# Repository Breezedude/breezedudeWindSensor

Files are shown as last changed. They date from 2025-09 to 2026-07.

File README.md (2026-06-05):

# BreezeDude Wind Sensor
### An open source low power FANET wind data transmitter.

Map of almost all wind stations: [breezedude.de](https://breezedude.de/)

### [Setup Guide & Tools](https://install.breezedude.de/)

For more info and documentation see the [Wiki](https://github.com/Breezedude/breezedudeWindSensor/wiki) and also [Discussion](https://github.com/Breezedude/breezedudeWindSensor/discussions)

PCB files have been moved to [this repo](https://github.com/Breezedude/breezedudeWindSensor-pcb)

----
<p align="center">
  <
  Breezedude Windstation
  Breezedude Windstation <br>
  <br>
</p>

A low cost FANET wind station using Ecowitt WS80/WS85 ultrasonic or DAVIS 6410 analog sensor.     
USB MSC Settings file and Drag&Drop Firmware upgrade. 

- Wind sensor: Ecowitt WS80/WS85 or analog with reed/potentiometer (e.g. DAVIS 6410)
- Barometric pressure sensor: **HP303B**, BMP280, BMP3xx or SPL06-001
- LoRa module: RFM95W (SX1276), G-NiceRF SX1262, **LLCC68**
- Antenna connector: SMA
- Microcontroller: SAMD21
- Connectivity: USB-C, I2C, 2x UART
- Battery: 1S Li-Ion 16340 750mAh (or 1-3x 18650 external)
- Solar: 5V
- PCB Size: 53x22mm

Currently using a 60x60 5V solar panel.     
Avg. power consumption at 40s send interval @3.7V battery: 0.4mA with analog sensor, 0.80mA with WS85, 1.22mA with WS80
 
Based on SMAD21 using [adafruits samd core](https://github.com/adafruit/ArduinoCore-samd) and itsybitsy M0 variant definitions and [bootloader](https://github.com/adafruit/uf2-samdx1).     

#### Related projects and inspiration:
* https://github.com/gereic/GXAirCom
* https://github.com/jgromes/RadioLib
* https://github.com/3s1d/fanet-stm32

If you like this project



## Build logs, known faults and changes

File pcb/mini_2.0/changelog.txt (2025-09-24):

2025-09-24:
V2.3:
* Added 10k pullup to Ssensor UART RX to aboid wakeup when no sensor is connected/cable failiure
* Replaced CN3063 with TP4057 for better avaliability.
* Moved SWD connector for better acessibility
* RF optimisation

2025-04-17:
V2.2:
* economic version with HP203B barometer and Vollgo CC68 868MHz LoRa radio module

2024-12-18: 
Mini V2.0
* Based on alpha 1.4, remade in KiCAD
* Removed heater support (DCDC)
* Changed to linear PV charger (CN 3063)
* TQPF48 package for SAMD21 (cheaper on JLCPCB, better thermal stress durability)
* TVS diodes for all external wiring
* BMP388 baro option
* Second (red) LED for error display
* Onboard battery holder for 16340 (CR123A size)

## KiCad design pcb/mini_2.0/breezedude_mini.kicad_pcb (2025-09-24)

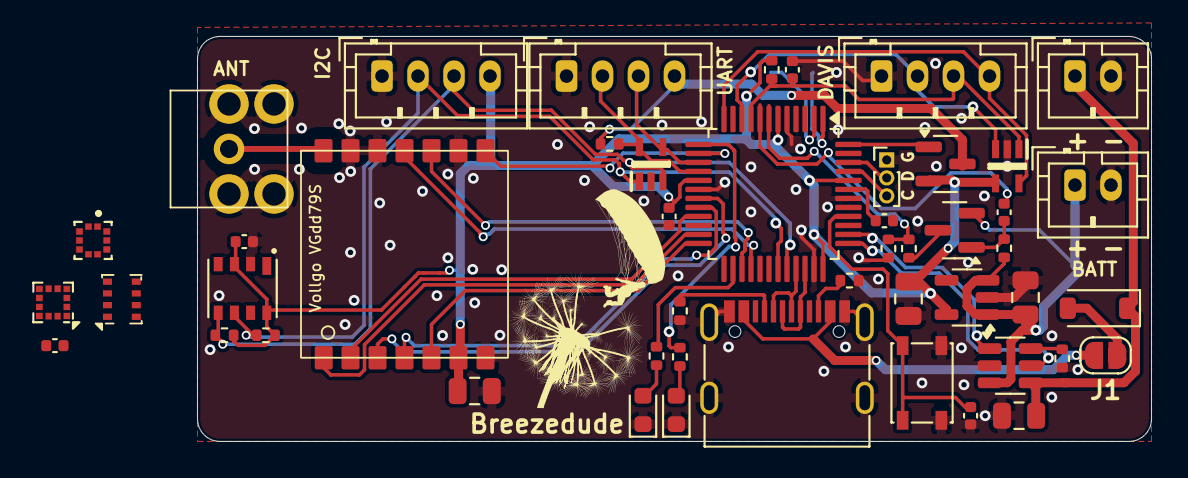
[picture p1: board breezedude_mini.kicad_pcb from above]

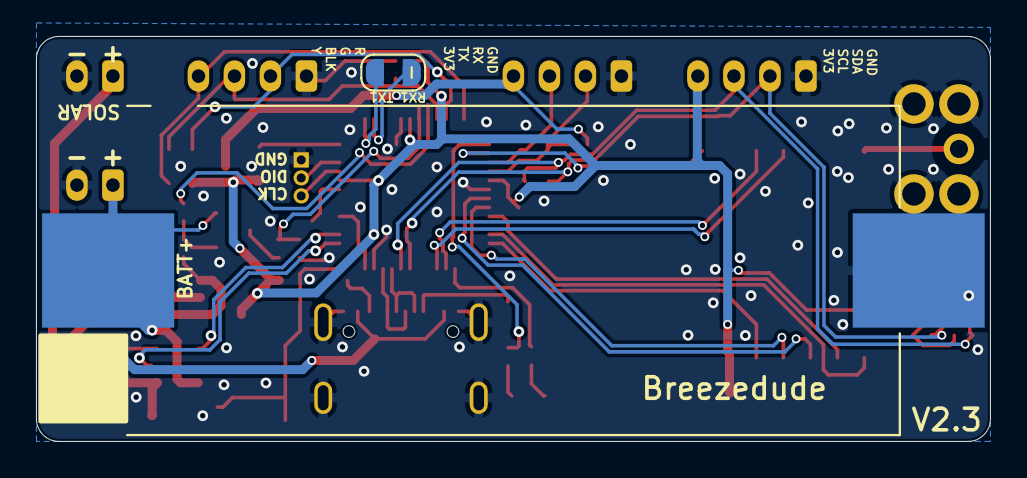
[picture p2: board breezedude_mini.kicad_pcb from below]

Board: 2 copper layers, 53.0 x 22.5 mm, 50 parts (2 on the bottom side), 46 nets.

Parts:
AE1: Antenna_Shield; sma_edge_6.5mm_vert
BT1: 1050; BAT_1050
C1, C3, C4, C12: 47u 6.3V; C_0805_2012Metric
C2, C6, C8: 10u 6.3V; C_0402_1005Metric
C5, C9, C11: 100n 16V; C_0402_1005Metric
C10: 220n 16V; C_0402_1005Metric
D1, D2: SMF3.3.TCT; SOT65P210X110-5N
D3: LED blue; LED_0603_1608Metric
D4: LED red; LED_0603_1608Metric
D5: Diode; D_SOD-123
J1, J6: Conn_01x02_Pin; JST_PH_B2B-PH-K_1x02_P2.00mm_Vertical
J2, J3, J5: Conn_01x04_Pin; JST_PH_B4B-PH-K_1x04_P2.00mm_Vertical
J4: Conn_01x03_Pin; PinHeader_1x03_P1.00mm_Vertical
J7: USB_C_Receptacle_USB2.0_16P; USB_C_Receptacle_G-Switch_GT-USB-7010ASV
J8: Conn_01x02_Pin; SolderJumper-2_Open_Gap1mm
JP1: SolderJumper_2_Open; SolderJumper-2_P1.3mm_Open_RoundedPad1.0x1.5mm
Q1, Q2: P-MOS; SOT-23
R1, R3, R12: 10k; R_0402_1005Metric
R2, R5: 100k; R_0402_1005Metric
R4: 330k; R_0402_1005Metric
R6: 470; R_0402_1005Metric
R7: 200; R_0402_1005Metric
R8, R9: 3.3k; R_0402_1005Metric
R10, R11: 5.1k; R_0402_1005Metric
SW1: SW_Push; SW_SPST_PTS810
U2: STLQ015M33R; SOT-23-5
U3: ATSAMD21G18A-A; TQFP-48_7x7mm_P0.5mm
U4: LIS2MDL; LGA-12_2x2mm_P0.5mm
U5: BMP280; Bosch_LGA-8_2x2.5mm_P0.65mm_ClockwisePinNumbering
U6: vollgo_vgdd79s868n0s1
U7: BMP388; PQFN50P200X200X80-10N
U8: HP203B; HP203B-LGA8
U9: TP4057; TSOT-23-6

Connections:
3V3: C4.2, C6.2, C8.2, C12.2, D1.4 (I/O4), J2.4, Q1.2 (S), R2.1, R8.2, R9.2, U2.5 (VOUT), U3.6 (VDDANA), U3.17 (VDDIO), U3.36 (VDDIO), U3.44 (VDDIN), U4.9 (Vdd), U4.10 (Vdd_IO), U5.2 (CSB), U5.6 (VDDIO), U5.8 (VDD), U6.6 (VCC), U7.1 (VDDIO), U7.6 (CSB), U7.10 (VDD), U8.3 (VDD), U8.8 (CSB)
/ANT: AE1.1 (A), U6.14 (ANT)
/BATT+: BT1.P, C3.2, J1.1, Q2.2 (S), R3.1, U2.1 (VIN), U2.3 (EN), U9.3 (BAT)
/DAVIS_DIR: D1.3 (I/O3), J3.2, U3.10 (PA05)
/DAVIS_POWER: D1.5 (I/O2), J3.4, U3.12 (PA07)
/DAVIS_SPEED: C5.1, D1.1 (I/O1), J3.3, R2.2, U3.9 (PA04)
/LED1: R6.1, U3.26 (PA17)
/LED2: R7.1, U3.13 (PA08)
/LORA_CS: U3.24 (PA15), U6.5 (CS)
/LORA_DIO1: U3.27 (PA18), U6.10 (DIO1)
/LORA_DIO2: U3.28 (PA19), U6.11 (BUSY)
/LORA_DIO3: U3.14 (PA09), U6.8 (DIO3)
/LORA_MISO: U3.21 (PA12), U6.2 (MISO)
/LORA_MOSI: U3.19 (PB10), U6.3 (MOSI)
/LORA_RESET: U3.23 (PA14), U6.1 (RST)
/LORA_SCK: U3.20 (PB11), U6.4 (SCK)
/PV_CHARGE: U3.38 (PB23), U9.1 (~CHRG)
/PV_DONE: U3.37 (PB22), U9.5 (STDBY)
/RESET: C11.2, SW1.1, U3.40 (~RESET)
/RX: D2.5 (I/O2), J5.2, R12.1, U3.16 (PA11)
/RX1: J8.2, U3.2 (PA01)
/SCL: D2.3 (I/O3), J2.3, R8.1, U3.32 (PA23), U4.1 (SCL/SPC), U5.4 (SCK), U7.2 (SCK), U8.5 (SCL)
/SDA: D2.1 (I/O1), J2.2, R9.1, U3.31 (PA22), U4.4 (SDA/SDI/SDO), U5.3 (SDI), U7.4 (SDI), U8.6 (SDA)
/SOLAR+: C1.2, D5.1 (K), J6.1, U9.4 (V_{CC})
/SWDCLK: J4.3, U3.45 (PA30)
/SWDIO: J4.2, U3.46 (PA31)
/TX: D2.4 (I/O4), J5.3, U3.15 (PA10)
/TX1: J8.1, U3.1 (PA00)
/USB_N: J7.A7 (D-), J7.B7 (D-), U3.33 (PA24)
/USB_P: J7.A6 (D+), J7.B6 (D+), U3.34 (PA25)
/V_DIV: R4.2, R5.1, U3.7 (PB08)
/V_IMP: C9.2, U3.8 (PB09)
GND: AE1.2 (Shield), BT1.N, C1.1, C2.1, C3.1, C4.1, C5.2, C6.1, C8.1, C10.2, C11.1, C12.1, D1.2 (GND), D2.2 (GND), D3.1 (K), D4.1 (K), J1.2, J2.1, J3.1, J4.1, J5.1, J6.2, J7.A1 (GND), J7.A12 (GND), J7.B1 (GND), J7.B12 (GND), J7.S1 (SHIELD), R1.2, R5.2, R10.2, R11.2, SW1.2, U2.2 (GND), U3.5 (GNDANA), U3.18 (GND), U3.35 (GND), U3.42 (GND), U4.6 (GND), U4.8 (GND), U5.1 (GND), U5.7 (GND), U6.7 (GND), U6.9 (GND), U6.12 (GND), U6.13 (GND), U7.3 (VSS), U7.5 (SDO), U7.8 (VSS), U7.9 (VSS), U8.2 (GND), U9.2 (GND)
unnamed: D3.2 (A), R6.2
unnamed: D4.2 (A), R7.2
unnamed: D5.2 (A), JP1.2 (B)
unnamed: J7.A5 (CC1), R10.1
unnamed: J7.B5 (CC2), R11.1
unnamed: J7.A4 (VBUS), J7.A9 (VBUS), J7.B4 (VBUS), J7.B9 (VBUS), JP1.1 (A)
unnamed: Q2.3 (D), R4.1
unnamed: C9.1, Q2.1 (G), R3.2
unnamed: C2.2, U3.43 (VDDCORE)
unnamed: C10.1, U4.5 (C1)
unnamed: R1.1, U9.6 (PROG)
SW_WS: Q1.1 (G), U3.48 (PB03)
VCC_WS: J5.4, Q1.3 (D), R12.2

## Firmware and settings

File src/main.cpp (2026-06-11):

#include <Arduino.h>
#include <Adafruit_TinyUSB.h>
#include <array>
#include "wiring_private.h" // pinPeripheral() function


#include "defines.h"
#include "hist.h"
#include "sensors.h"
#include "logging.h"
#include "sleep.h"
#include "fanet.h"
#include "display.h"
#include "tools.h"
#include "radio.h"
#include "ota_ab.h"
#include "ota_lora.h"

#ifndef BREEZEDUDE_DEVELOP_MODE
#define BREEZEDUDE_DEVELOP_MODE 0
#endif


// Todo list:
// * Read bootloader version
// * detect sensor frozen?

// https://github.com/adafruit/Adafruit_TinyUSB_Arduin
// https://github.com/adafruit/ArduinoCore-samd
// https://github.com/Microsoft/uf2
// https://github.com/adafruit/uf2-samdx1

// Serial2 for Degugging on HW > 1.3
Uart Serial2(&sercom1, PIN_SERCOM1_RX, PIN_SERCOM1_TX, SERCOM_RX_PAD_1, UART_TX_PAD_0 ) ;

// WS85 with UART
WS85WindSensor ws85uart(&Serial1);

// Pulsecounter
volatile uint32_t pulsecount =0; // pulses from wind speed sensor using reed switch

// WDT and CPU Clock
#define WDT_PERIOD 2500 // ms for wdt to wait to reset mcu if not reset in time

int div_cpu = 1; // current div
bool first_sleep = true; // first sleep after reset, USB perephial could still be on
bool usb_connected = false;
uint32_t next_tx_time = 0;
uint32_t boot_usb_hold_until_ms = 0;

uint32_t sleep_allowed = 0; // time() when is is ok so enter deepsleep
bool reduced_interval = false; // reduced interval active
bool undervoltage = false;
bool deep_undervoltage = false; // set after 3 consecutive voltage readings < 2.9V; triggers extended sleep for solar charging

// ### Variables for storing settings from file, may be overewritten #####

bool use_mcp4652 = true; // used on first version of PCB (<=1.3) to set MPPT and DCDC voltage

bool settings_ok = false;
static uint32_t no_settings_first_seen_ms = 0; // set on first !settings_ok wakeup


// Message timing

uint32_t last_msg_weather = 0;
uint32_t last_msg_name = 0;
uint32_t last_msg_info = 0;

uint32_t broadcast_scale_factor = 1; // multiplier for broadcast values. is set to 2..5 if battery is low


uint32_t last_fnet_send = 0; // last package send
uint32_t fanet_cooldown = 4000;
uint32_t loopcounter = 0;
bool force_wait_for_wdata = false;

volatile int wakeup_source = WAKEUP_NONE;

// Sleep ----------------------------------------------------------------------------------------------------------------------

// dummy function
void wakeup_EIC(){
  wakeup_source = WAKEUP_EIC;
}

void mark_uart_wakeup(){
  wakeup_source = WAKEUP_UART;
}

static bool usb_host_connected(){
  // Use USB enumeration as primary signal. DTR remains a fallback for hosts
  // that do not expose mount state reliably.
  return TinyUSBDevice.mounted() || usb_connected || Serial.dtr();
}

static bool keep_usb_active_during_sleep(){
  return usb_host_connected();
}

uint32_t sleep(bool enable_uart_interrupt){
  // Reset the wake reason before each sleep cycle so spurious USB IRQs can be ignored.
  wakeup_source = WAKEUP_NONE;

  // Disable Debug uart
  //if(debug_enabled()){
  //  DEBUGSER.end();
  //}

  // disable wdt during sleep
  if(settings.use_wdt) {
    wdt_disable();
  }

  if(enable_uart_interrupt){
    if(is_wsxx() || settings.sensor_type == s_WS85_UART || settings.sensor_type == s_WINDNERD){
      enable_sercom0_int();
      //log_i("Enable UART Interrupt\r\n");
    }
  }
  if(usb_host_connected()){
    log_flush();
  }
  reset_time_counter(); // start counting sleeptime from zero
  bool keep_usb = keep_usb_active_during_sleep();

  // With USB test mode active we use light sleep and ignore wakeups that do not
  // set a wakeup source, otherwise USB IRQ traffic would break the normal flow.
  do {
    deepsleep(keep_usb);
  } while (keep_usb && wakeup_source == WAKEUP_NONE);
  uint32_t p = micros();



  if(is_wsxx() || settings.sensor_type == s_WINDNERD){
    disable_sercom0_int();
    p = micros()-p;
    //DEBUGSER.println(p);
    SENSOR_UART.begin(115200*div_cpu);
  }

  if(settings.sensor_type == s_WS85_UART) {
    disable_sercom0_int();
    ws85uart.begin(div_cpu); // required to get data
  }

  uint32_t t = read_time_counter();

  sleeptime_cum += t; // add slept time to global time counter. Should be done directly after wakeup but we need every tick to get UART working first

  // Disable Debug uart again
  //if(debug_enabled()){
  //  DEBUGSER.begin(115200*div_cpu);
  //}
  // re-enable wdt after sleep
  if(settings.use_wdt) {
    wdt_enable(WDT_PERIOD, false);
  }
  return t;
}

// called after sleep
void wakeup(){
  // USB->DEVICE.CTRLA.reg |= USB_CTRLA_ENABLE; // Re-enable USB, no need, not working?
  loopcounter = 0;
  pinMode(PIN_V_READ_TRIGGER, OUTPUT); // prepare voltage measurement, charge trigger cap
  digitalWrite(PIN_V_READ_TRIGGER,1);
  log_i("\r\n########\r\n");
  log_i("Wakeup: ", time()); 
  log_v("Wakeup source: "); log_v(wakeup_source_string[wakeup_source]);log_v("\r\n");
  wakeup_source = WAKEUP_NONE;

  // In !settings_ok mode: after the first 5 minutes, flash the red LED only while awake.
  if (!settings_ok && no_settings_first_seen_ms != 0 &&
      (millis() - no_settings_first_seen_ms) >= 300000UL) {
    led_error(1);
  }



  get_solar_charger_state();
  if(settings.use_baro){
    baro_start_reading(); // request data aquisition, will be read later
  }
  if(settings.use_imu){
    get_imu();
  }

  read_batt_perc();
  sleep_allowed = time() + 100; // go back to sleep after 6 secs as fallback
}

uint32_t timeToSend(int last, int interval) {
  if (interval) {
    int delay = interval * broadcast_scale_factor;
    int elapsed = time() - last;
    return (elapsed < delay) ? (delay - elapsed) : 0;
  }
  return -1;
}

enum TxAttemptResult : uint8_t {
  TX_ATTEMPT_NONE = 0,
  TX_ATTEMPT_STARTED,
  TX_ATTEMPT_DEFERRED_LBT,
};

// LBT (Listen Before Talk) checks whether the LoRa channel is free before TX.
// The radio is first taken out of RX sleep and prepared for transmission.
// If LBT is enabled, a CAD/channel scan is executed to detect ongoing LoRa activity.
// When the channel is free, the packet is transmitted normally and TX done is handled by IRQ.
// When the channel is busy, no packet is sent and the scheduler retries after a random 0-2 s delay.
// If LBT is disabled, the scan is skipped and transmission starts immediately.
static TxAttemptResult start_lbt_transmit(const uint8_t *data, size_t len) {
  dis_rx_sleep();
  // Arm TX-done callback here (not in dis_rx_sleep) to avoid re-arming DIO1
  // while the radio is in the sleep path, which causes spurious IRQ on LLCC68.
  radio_phy->setPacketSentAction(set_fanet_send_flag);
  if(!settings.lora_lbt) {
    radio_phy->startTransmit(data, len);
    return TX_ATTEMPT_STARTED;
  }
  if(!lbt_channel_free()) {
    radio_sleep();
    return TX_ATTEMPT_DEFERRED_LBT;
  }
  radio_phy->startTransmit(data, len);
  return TX_ATTEMPT_STARTED;
}

static uint32_t next_lbt_retry_delay() {
  return (millis() ^ (time() << 1) ^ get_fanet_id()) % 2001;
}

static void defer_next_send(uint32_t &last_msg, uint32_t interval, const char *label) {
  uint32_t retry_delay = next_lbt_retry_delay();
  uint32_t scaled_interval = interval * broadcast_scale_factor;
  last_msg = time() - scaled_interval + retry_delay;
  next_tx_time = time() + retry_delay;
  sleep_allowed = time() + 1;

  log_i("LBT: defer ");
  log_i(label);
  log_i(" TX by ms: ", retry_delay);
  log_i("\r\n");
}

// calc time to sleep til next fanet message needs to be send
uint32_t calc_time_to_sleep(){
  uint32_t tts_weather = -1;
  uint32_t tts_name = -1;
  uint32_t tts_info = -1;
  uint32_t tts = 0;
  static uint32_t last_print = 0;

  if(sensor.batt_volt){
    if(undervoltage){
      tts = 1000*30*60; // sleep 30min
      broadcast_scale_factor = 5;
      next_tx_time = time()+tts;
      return tts;
    } else if(sensor.batt_volt < settings.reduce_interval_voltage){
      reduced_interval = true;
      broadcast_scale_factor = 3;
      log_i("Low voltage\r\n");
    } else {
      // battery voltage is normal
      reduced_interval = false;
      broadcast_scale_factor = 1;
    }
  }

// Undervoltage Voltage behavior (WS85 connected):
// * 2439mV: sleeps @ 5.90µA
// * 2560mV: deepsleeps @9.20µA
// * 2650mV: deepsleep 11.70µA
// * 2754mV. when in depsleep stays there @ 15µA, on reset goes to brownout drawwing 1,47mA
// ** when us-uart power mosfeet weakens, current draw rises until ws85 starts working, drawing 7.55mA oveer UART

// * <2800mV: Brownout, draws 4mA, boots to bootloader on wake, never comes back
// * > 2800mV. resets normally, goes to deepsleep 17µA for 30min
// * 2800-3100mV: Undervoltage, draws 20µA in sleep, stays in sleep for 1800000ms (=30min) before waking up to check voltage again




  tts_weather = timeToSend(last_msg_weather, settings.broadcast_interval_weather);
  tts_name    = timeToSend(last_msg_name, settings.broadcast_interval_name);
  tts_info    = ota_lora_next_hwinfo_due_ms();


  
  tts = min(min(tts_name, tts_info), tts_weather);
  if( fanet_cooldown && last_fnet_send  && (time() - last_fnet_send + tts < fanet_cooldown)){
    tts += fanet_cooldown - (time()-last_fnet_send);
  }

    if(millis()-last_print > 2500){
    last_print = millis();
    log_v("tts_weather: ", tts_weather);
    log_v("tts_name: ", tts_name);
    log_v("tts_info: ", tts_info);
    log_v("tts: ", tts);
  }

  if(tts == (uint32_t)-1){ tts=0;}
  

  if( !tts && loopcounter > 25){
    log_e("just looping, will sleep\r\n");
    tts = 12000; // set to sleep to keep updating sensor data
  }

  next_tx_time = time()+tts;

  
  return tts;
}

// RTC Handler callback, do not rename. gets called on rtc (timer) interrupt
void RTC_Handler(void){
  if (RTC->MODE1.INTFLAG.bit.OVF && RTC->MODE1.INTENSET.bit.OVF) {  // Check if an overflow caused the interrupt
    RTC->MODE1.INTFLAG.bit.OVF = 1;                                 // Reset the overflow interrupt flag
    wakeup_source = WAKEUP_RTC;
  }
}

// shut everything down, enable deepsleep
void go_sleep(){
  bool keep_usb = keep_usb_active_during_sleep();

  pinDisable(PIN_V_READ_TRIGGER);

// shut down the USB peripheral
  if(first_sleep && !keep_usb){
    log_i("Disable USB\r\n");
    usb_ignore_detach_event = true;
    USB->DEVICE.CTRLA.bit.ENABLE = 0;                   
    while(USB->DEVICE.SYNCBUSY.bit.ENABLE){};
    first_sleep = false;
    usb_connected = false;

    if(set_cpu_div(settings.div_cpu_slow)){ // USB test mode keeps 48MHz; only lower the clock for real low-power sleep.
      div_cpu = settings.div_cpu_slow;
      DEBUGSER.begin(115200*div_cpu); // F_CPU ist still 48M, so every clock needs to by multiplied manually
    }
  }

  uint32_t time_to_sleep = calc_time_to_sleep();
  // One-shot wait window when weather TX is due but wind data is stale.
  if (force_wait_for_wdata) {
    time_to_sleep = 12000UL;
    force_wait_for_wdata = false;
  }
  if(time_to_sleep == 0){ return;} // if time_to_sleep = 0, do not sleep at all
  rtc_sleep_cfg(time_to_sleep);

  if(deep_undervoltage){
    radio_sleep();
    log_i("Deep UV (<2.9V). Sleeping until solar charges or voltage recovers\r\n");
    log_flush();
    // PV_CHARGE (PB23) is active-LOW: falls LOW when the solar charger draws ~3mA.
    // INPUT_PULLUP ensures pin is HIGH (defined state); EIC only fires on genuine FALLING edge.
    // Without this, the floating pin (left hi-Z by get_solar_charger_state) triggers EIC immediately.
    pinMode(PIN_PV_CHARGE, INPUT_PULLUP);
    attachInterruptWakeup(PIN_PV_CHARGE, wakeup_EIC, FALLING, false);
    do {
      rtc_sleep_cfg(524000UL); // max RTC period ~8.7 min per cycle
      sleep(false);
      read_batt_perc(); // updates deep_undervoltage and undervoltage via voltageToSOCNonLinear
      log_i("Deep UV wake: V=", sensor.batt_volt);
      log_flush();
    } while (deep_undervoltage && wakeup_source != WAKEUP_EIC);
    detachInterrupt(digitalPinToInterrupt(PIN_PV_CHARGE));
    pinDisable(PIN_PV_CHARGE);
    wakeup();
    return;
  }

  if(undervoltage){
    radio_sleep(); // ensure radio is in PHY sleep and DIO1 interrupt is detached
    log_i("Undervoltage. will sleep for ", time_to_sleep);
    log_flush();
    sleep(false); // will sleep in 30min blocks with 70µA current draw until battery recovers.
    wakeup(); // re-read battery so undervoltage clears if voltage has recovered
    return; // do not read sensors
  }

  if(settings.sensor_type == s_DAVIS6410){ 
    time_to_sleep = min(time_to_sleep, settings.sensor_integration_time);  // interval for gust detection 
    rtc_sleep_cfg(time_to_sleep);
  }

  // move to setup function
  if(!settings_ok){
    // No valid settings: sleep 12s per cycle so OTA config updates can still arrive.
    // Keep the red LED on for the first 5 minutes, then only while awake.
    if (no_settings_first_seen_ms == 0) {
      no_settings_first_seen_ms = millis();
    }
    bool in_first_5min = (millis() - no_settings_first_seen_ms) < 300000UL;
    if (in_first_5min) {
      led_error(1);  // stay on continuously during first 5 minutes
    } else {
      led_error(0);  // turn off before sleep; wakeup() will re-enable it briefly
    }
    log_e("No settings file\r\n");
    time_to_sleep = 12000UL;
  }

  //if(!time_to_sleep){ return;} // if time_to_sleep = 0, do not sleep at all

  if(time_to_sleep > 200000UL) {
    log_i("will sleep for s: ", time_to_sleep / 1000);
  } else {
    log_i("will sleep for ms: ", time_to_sleep);
  }
  log_flush();

  // Ensure radio is in the correct state for the sleep window (RX if conditions
  // are met, PHY sleep otherwise). This also covers the period before the first
  // TX, when radio_sleep() has not yet been called from the TX-done path.
  radio_sleep();
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
void loop(){

static uint32_t send_active=0; // if > 0, time() last message was send to tx queue, reset to 0 if send is complete
static uint32_t last_settings_check = 0; // timee() ckecked if a settings file is present if settings not read yet sucessfully

// print millis as alive counter
static uint32_t last_call = 0;
static bool s = false;

loopcounter++;

  if(settings.use_wdt){
    wdt_reset();
  }

  // If enumeration completes shortly after startup, still arm the boot hold.
  if(!boot_usb_hold_until_ms && usb_host_connected()) {
    boot_usb_hold_until_ms = millis() + 10000UL;
    log_i("USB connected after boot, keep awake for 10s\r\n");
  }

  bool boot_usb_hold_active = (boot_usb_hold_until_ms != 0) && ((int32_t)(millis() - boot_usb_hold_until_ms) < 0);

  if(last_call && (time()-last_call > 15)){
    if(!s){led_status(0);}
  }

  // Always poll CDC commands so TEST_USB can switch from USB wait mode into the
  // normal sleep/wakeup flow without requiring a reboot.
  read_serial_cmd();
  handle_usb_link_watchdog();

  // Hard-stop normal operation until a valid user configuration is present.
  if(!settings_ok){
    if(!sleep_allowed){
      sleep_allowed = time() + 180000UL; // sleep after 3 minutes
    }
    if(time() - last_settings_check > 15000){
      last_settings_check = time();
      log_e("\r\nFailed to obtain valid settings. Waiting for user config\r\n");
      settings_ok = parse_file(SETTINGSFILE);
      if(settings_ok){
        NVIC_SystemReset();
      }
    }
    if((time() > 5UL*60UL*1000UL)){
      led_error(0);
    }
    if(settings.use_wdt){
      wdt_reset();
    }
    return;
  }

  if(settings.use_baro){read_baro();}
  #if BREEZEDUDE_ENABLE_GPS
  if(settings.use_gps){read_gps();}
  #endif

  if(!ota_lora_busy() && fanet_cooldown_ok() && settings.broadcast_interval_name && ( (time()- last_msg_name) > (settings.broadcast_interval_name* broadcast_scale_factor)) ){ // once a hour
    if(settings.station_name.length() > 1){
      led_status(1);
      TxAttemptResult tx_result = send_msg_name(settings.station_name.c_str(),settings.station_name.length());
      if(tx_result == TX_ATTEMPT_STARTED) {
        log_i("Send name: "); log_i(settings.station_name.c_str()); log_i("\r\n");
        last_fnet_send = time();
        last_msg_name = time();
        send_active = time();
      } else if(tx_result == TX_ATTEMPT_DEFERRED_LBT) {
        defer_next_send(last_msg_name, settings.broadcast_interval_name, "name");
      }
      led_status(0);
    }
  }

  if(!ota_lora_busy() && fanet_cooldown_ok() && settings.broadcast_interval_weather && ( (time()- last_msg_weather) > (settings.broadcast_interval_weather * broadcast_scale_factor)) ){
    if( allowed_to_send_weather() ){
      TxAttemptResult tx_result = send_msg_weather();
      if(tx_result == TX_ATTEMPT_STARTED) {
        last_fnet_send = time();
        last_msg_weather = time();
        send_active = time();
      } else if(tx_result == TX_ATTEMPT_DEFERRED_LBT) {
        defer_next_send(last_msg_weather, settings.broadcast_interval_weather, "weather");
      } else if(tx_result == TX_ATTEMPT_NONE) {
        // no valid wind data yet, retry in 10 seconds
        last_msg_weather = time() - (settings.broadcast_interval_weather * broadcast_scale_factor) + 10000;
        sleep_allowed = time() + 1;
        log_i("Weather TX skipped, retry in 10s\r\n");
      }
    } else {
      if((is_wsxx() || settings.sensor_type == s_WS85_UART) && sensor.last_data && !sensor.next_baro_reading && (time()- sensor.last_data > 10000)){
        const uint32_t wdata_age = time() - sensor.last_data;
        log_i("Wdata not ready. Wdata age: ", (time()- sensor.last_data) );
        log_i("Last Baro reading age: ", (time()- sensor.last_baro_reading) );
        if(wdata_age > 3600000UL){
          log_e("Wind data stale > 1h, restarting to recover\r\n");
          log_flush();
          NVIC_SystemReset();
        }
        force_wait_for_wdata = true;
        sleep_allowed = time();
        //sensor.last_data = 0;
      }
      
    }
  }
  const uint32_t info_due_ms = ota_lora_next_hwinfo_due_ms();
  if(!ota_lora_busy() && fanet_cooldown_ok() && info_due_ms == 0u ){
      led_status(1);
      TxAttemptResult tx_result = send_msg_info();
      if(tx_result == TX_ATTEMPT_STARTED) {
        last_fnet_send = time();
        last_msg_info = time();
        send_active = time();
      } else if(tx_result == TX_ATTEMPT_DEFERRED_LBT) {
        uint32_t retry_delay = next_lbt_retry_delay();
        ota_lora_defer_hwinfo_retry(retry_delay);
        next_tx_time = time() + retry_delay;
        sleep_allowed = time() + 1;
        log_i("LBT: defer info TX by ms: ", retry_delay);
        log_i("\r\n");
      }
      led_status(0);
  }

  if(send_active){
    if( (time()- send_active > (3500))){
      led_error(1);
      log_i("Send timed out\r\n");
      led_status(0);
      send_active =0;
      sleep_allowed = time() + (1);
      radio_sleep(); // radio_phy->sleep();
      delay(10);
      led_error(0);
    }

    if(transmittedFlag){
      transmittedFlag = false;
      send_active = 0;
      sleep_allowed = time() + (1);
      radio_phy->finishTransmit();
      if(!ota_lora_on_tx_complete()) {
        radio_sleep(); // radio_phy->sleep();
      }
    }
  }

  if(!send_active && ota_lora_poll()) {
    sleep_allowed = time() + 1;
  } else if(settings.lora_smart_rcv || settings.repeater){
    if(fanet_rx() && !send_active) {
      // readData() in fanet_rx() left radio in standby; re-arm RX now that we
      // know no TX is in progress (avoids clearing the TX-done DIO1 handler).
      radio_sleep();
    }
  }

  if(!send_active && !ota_lora_busy() && (settings.lora_smart_rcv || settings.repeater)) {
    if(fanet_forward_check()) {
      send_active = time();
    }
  }

  if(settings.analog_test_mode){
    forward_analog_test_serial();
  }

// Check if everything is done --> sleep
  if(!settings.analog_test_mode && !send_active && !ota_lora_busy() && !boot_usb_hold_active && sleep_allowed && (time() > sleep_allowed) && (time() > 2500)){ // allow sleep after 2500 ms to get a chance to detect USB / CDC commands
    go_sleep();
  }

  /*
  
  if(usb_connected){
    // keep usb alive for 15 min. Its not easyly possible to detect if still connected, so just restart after 15min
    if(!settings.test_with_usb && (time() > 15UL*60UL*1000UL)){
      log_i("Restart\r\n");
      log_flush();
      usb_ignore_detach_event = true;
      usb_connected = false; // clear before reset so disconnect detector above is not triggered
      NVIC_SystemReset();
    }
  }
*/

  if((time() > 5UL*60UL*1000UL)){ // trun off error LED after 5minutes to save energy if an error occures with no one around
    led_error(0);
  }

  if(settings.use_wdt){
    wdt_reset();
  }
}

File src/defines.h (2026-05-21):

#pragma once

#define BROADCAST_INTERVAL 40*1000UL // dafault value,  overwritten by settingfile

#define LORA_FREQ_EU 868.2
#define LORA_BW_EU 250
#define LORA_FREQ_NA 920.8
#define LORA_BW_NA 500

#define DEBUGSER Serial2
#define SENSOR_UART Serial1
#define GPS_SERIAL Serial1 // if no WS80 is connected a GPS receiver can be used. Mainly for OGN range/coverage check

// https://github.com/adafruit/ArduinoCore-samd/blob/master/variants/itsybitsy_m0/variant.cpp
// 0 { PORTA, 11, PIO_SERCOM, (PIN_ATTR_DIGITAL), No_ADC_Channel, NOT_ON_PWM, NOT_ON_TIMER, EXTERNAL_INT_11 }, // RX: SERCOM0/PAD[3]
// 1 { PORTA, 10, PIO_SERCOM, (PIN_ATTR_DIGITAL), No_ADC_Channel, NOT_ON_PWM, NOT_ON_TIMER, EXTERNAL_INT_10 }, // TX: SERCOM0/PAD[2]

// SERCOM 4 - SPI RFM95W LoRa
#define PIN_LORA_MISO MISO  // 28 PA12  - SERCOM2/PAD[0] | alt SERCOM4/PAD[0]
#define PIN_LORA_MOSI MOSI  // 29 PB10  -                | alt SERCOM4/PAD[2]
#define PIN_LORA_SCK SCK    // 30 PB11  -                | alt SERCOM4/PAD[3]

#define PIN_LORA_CS 5    // PA15 - SERCOM2/PAD[3] | alt SERCOM4/PAD[3]
#define PIN_LORA_RESET 2 // PA14 - SERCOM2/PAD[2] | alt SERCOM4/PAD[2]
#define PIN_LORA_DIO0 11 // PA16 - SERCOM1/PAD[0] | alt SERCOM3/PAD[0]
#define PIN_LORA_DIO1 10 // PA18 - SERCOM1/PAD[2] | alt SERCOM3/PAD[2]
#define PIN_LORA_DIO2 12 // PA19 - SERCOM1/PAD[3] | alt SERCOM3/PAD[3]
#define PIN_LORA_DIO3 3  // PA09 - SERCOM0/PAD[1], ADC
#define PIN_PV_CHARGE 38// PB23
#define PIN_PV_DONE 37 // PB22
#define PIN_PS_WS 36 // PB03 PIO_SERCOM_ALT, PIN_ATTR_NONE, No_ADC_Channel, NOT_ON_PWM, NOT_ON_TIMER, EXTERNAL_INT_NONE },  // SPI Flash MISO on ItsyBitsy M0, Power switch control for WSXX Sensor. HW >= 2.2

// Serial2
#define PIN_SERCOM1_TX 40 // PA00 SERCOM1 PAD0
#define PIN_SERCOM1_RX 41 // PA01 SERCOM1 PAD1

// Pins with solder jumpers 
#define PIN_ID0 6 // PA20 - SERCOM5/PAD[2]
#define PIN_ID1 7 // PA21 - SERCOM5/PAD[3]


#define FANET_VENDOR_ID 0xBD
#define VBATT_LOW 3.35 // Volt


#define PIN_DAVIS_SPEED 17 // A3 17 PA04
#define PIN_DAVIS_DIR 18 // A4 18 PA05
#define PIN_DAVIS_POWER 9 // 9 PA07 - power for direction potentiometer. Turn off if not used to save power. Old Pin, Hardware 2.4 uses PS_SENSOR

// SERCOM 3 - I²C Barometer / Digipot
#define PIN_SDA 26 // PA22
#define PIN_SCL 27 // PA23

// DAVIS6410 Pinout
// Black - Wind speed contact (closure to ground)
// Red - Ground
// Green - Wind direction pot wiper (20KΩ potentiometer)
// Yellow - Pot supply voltage

// SERCOM 0 - uart serial Sensor/ GPS / Debug
#define PIN_RX 0 // A6 PA11
#define PIN_TX 1 // A7 PA10

#define PIN_STATUSLED 13 // PA17 // blue, 1.2mA @ 2.77V = 470Ohm
#define PIN_ERRORLED 4 //D4/A8 PA08 // red 2.9mA @ 2.16V = 390Ohm
#define PIN_V_READ_TRIGGER A2 // D16 PB09
#define PIN_V_READ A1 // D15 PB08 - { PORTB,  8, PIO_ANALOG, (PIN_ATTR_PWM|PIN_ATTR_TIMER), ADC_Channel2, PWM4_CH0, TC4_CH0, EXTERNAL_INT_8 }, // ADC/AIN[2]

#define VERSIONFILE (char*) "version.txt"
#define SETTINGSFILE (char*) "settings.txt"



#define HISTORY_INTERVAL 30*1000 // 30s 3600*1000 // 1h
#define HISTORY_LEN 15*24 // in hours, 15 days

#define WIND_AGE 1000*30 // 30s history
#define GUST_AGE 1000*60*10 // 10 min history
#define WIND_HIST_STEP 1000*4 //ms history slots, 22 sek
#define WIND_HIST_LEN 150 // number so slots. should match GUST_AGE / GUST_HIST_STEP


enum ResParseChar {
  RESP_OK,
  RESP_ERROR,
  RESP_COMPLETE
};

enum LORA_MODULE{
  LORA_NONE,
  LORA_SX1276,
  LORA_SX1262,
  LORA_LLCC68
};

enum CHIP_BARO{
  BARO_NONE,
  BARO_BMP280,
  BARO_SPL06,
  BARO_BMP3xx,
  BARO_HP203B
};

enum CHIP_IMU{
  IMU_NONE,
  IMU_
};


enum Wakeup_Source{
  WAKEUP_NONE,
  WAKEUP_RTC,
  WAKEUP_EIC,
  WAKEUP_WDT,
  WAKEUP_UART,
  WAKEUP_LORA,
  WAKEUP_USB
};

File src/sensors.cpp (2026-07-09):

#include "sensors.h"
#include "sleep.h"
#include "wiring_private.h"

extern int div_cpu;
extern bool undervoltage;
extern bool deep_undervoltage;


#if BREEZEDUDE_ENABLE_GPS
TinyGPSPlus tinyGps;
#endif

// I2C Barometer
#if BREEZEDUDE_BARO_BMP280
BMP280 bmp280; // Bosch BMP280
#endif
#if BREEZEDUDE_BARO_SPL06
SPL06 spl; // Goertek SPL06-001
#endif
#if BREEZEDUDE_BARO_HP203B
HP203B hp; // HP203B 0x76 or 0x77
#endif
#if BREEZEDUDE_BARO_BMP3XX
Adafruit_BMP3XX bmp3xx;
#endif
QMC5883P qmc5883p; // GY-271
// DPS310 as alternative?


CHIP_BARO chip_baro = BARO_NONE;
CHIP_IMU chip_imu = IMU_NONE;

Sensors sensor;

void switch_sensor_power(bool state){
  static bool current_power_state = false;
  const bool uses_uart = (is_wsxx() || settings.sensor_type == s_WS85_UART || settings.sensor_type == s_WINDNERD);
  if(state && !current_power_state){ // turn on
    current_power_state = true;
    pinMode(PIN_PS_WS,OUTPUT);
    digitalWrite(PIN_PS_WS, 0);
    if(uses_uart){
      // Re-connect UART pins to SERCOM0 peripheral before the sensor can respond
      pinPeripheral(PIN_RX, PIO_SERCOM);
      pinPeripheral(PIN_TX, PIO_SERCOM);
      SENSOR_UART.begin(115200 * div_cpu);
      log_i("WS sensor power ON\r\n");
    }
  }
  if(!state && current_power_state){ // turn off
    current_power_state = false;
    digitalWrite(PIN_PS_WS, 1);
    if(uses_uart){
      // Disable UART pins so the idle-HIGH TX line cannot leak current into the
      // sensor through its input protection diodes when its VCC is removed.
      pinDisable(PIN_TX); // PA10 - UART idles HIGH, would source current into sensor
      pinDisable(PIN_RX); // PA11 - symmetric isolation
      log_i("WS sensor power OFF\r\n");
    }
  }
}

static uint8_t voltageToSOCNonLinear(float v) {
  if(v < 0.8f) {led_error(1); log_i("V_Batt read error: ", v); return 0;} // bad reading
  // Deep UV: 3 consecutive readings < 2.9V trigger extended sleep for solar charging recovery.
  // Hysteresis: clears when voltage rises above 3.0V.
  {
    static uint8_t deep_uv_count = 0;
    if (v < 2.9f) {
      if (deep_uv_count < 3) ++deep_uv_count;
      if (deep_uv_count >= 3) deep_undervoltage = true;
    } else if (v > 3.0f) {
      deep_uv_count = 0;
      deep_undervoltage = false;
    }
  }
  if(v < 3.15f) {switch_sensor_power(0); settings.uv_triggered = true; undervoltage = true; return 0;} // undervoltage, turn off sensor to save power
  if(v > 3.3f) {if(is_wsxx() || settings.sensor_type == s_WS85_UART || settings.sensor_type == s_WINDNERD){
                  switch_sensor_power(1);
                } undervoltage = false;}
  if(v > 4.15f){settings.uv_triggered = false; return 100;}

  // Piecewise linear OCV->SOC for 3.7V Li-Ion at low discharge rate.
  // Use compact integer tables to save flash; 1% SOC resolution is sufficient here.
  static const uint16_t vt_mv[] = { 3150, 3400, 3600, 3750, 3900, 4000, 4100, 4150 };
  static const uint8_t  st[]    = {    0,    5,   20,   50,   75,   88,   97,  100 };
  constexpr int N = 8;

  uint16_t v_mv = (uint16_t)(v * 1000.0f + 0.5f);
  if (v_mv <= vt_mv[0]) return 0;
  if (v_mv >= vt_mv[N-1]) return 100;

  for (int i = 1; i < N; i++) {
    if (v_mv <= vt_mv[i]) {
      uint16_t v0 = vt_mv[i - 1];
      uint16_t v1 = vt_mv[i];
      uint8_t s0 = st[i - 1];
      uint8_t s1 = st[i];
      uint32_t num = (uint32_t)(v_mv - v0) * (uint32_t)(s1 - s0) + (uint32_t)(v1 - v0) / 2u;
      return (uint8_t)(s0 + (num / (uint32_t)(v1 - v0)));
    }
  }
  return 100;
}

// Trigger ADC and calc battery value in percent and volts
void read_batt_perc(){
  static uint32_t last_battery_reading=0;
  // only sample if last reading is older than 100ms
  if(time()- last_battery_reading > 100){
    last_battery_reading = time();
    analogReference(AR_INTERNAL1V0);
    analogReadResolution(10);
    pinMode(PIN_V_READ, INPUT);

    // Extend ADC sampling phase via SAMPCTRL instead of software delays between reads.
    // ADC clock = 48 MHz / 512 ~= 94 kHz  ->  half-cycle ~= 5.3 us.
    // SAMPLEN=4 adds 5 half-cycles ~= 26 us extra sample time per conversion.
    //ADC->SAMPCTRL.reg = ADC_SAMPCTRL_SAMPLEN(4);
    //while (ADC->STATUS.bit.SYNCBUSY);

    constexpr int N_SAMPLES = 15;
    uint16_t samples[N_SAMPLES];
    digitalWrite(PIN_V_READ_TRIGGER,0);
    delayMicroseconds(50); // allow divider to settle
    for (int i = 0; i < N_SAMPLES; i++) {
      samples[i] = analogRead(PIN_V_READ);
    }
    digitalWrite(PIN_V_READ_TRIGGER,1);

    //ADC->SAMPCTRL.reg = ADC_SAMPCTRL_SAMPLEN(0); // restore default for other ADC users
    //while (ADC->STATUS.bit.SYNCBUSY);

    // Trimmed mean: discard min + max, average remaining N_SAMPLES-2
    uint16_t vmin = samples[0], vmax = samples[0];
    uint32_t vsum = 0;
    for (int i = 0; i < N_SAMPLES; i++) {
      vsum += samples[i];
      if (samples[i] < vmin) vmin = samples[i];
      if (samples[i] > vmax) vmax = samples[i];
    }
    float val = (float)(vsum - vmin - vmax) / (float)(N_SAMPLES - 2);

    pinDisable(PIN_V_READ);
    val *= 0.0040925; // 100k/330k 1.0V Vref

    // Moving average over last 5 readings to suppress short voltage dips
    constexpr int V_AVG_LEN = 5;
    static float v_history[V_AVG_LEN] = {0};
    static int v_idx = 0;
    static int v_count = 0;
    v_history[v_idx] = val;
    v_idx = (v_idx + 1) % V_AVG_LEN;
    if (v_count < V_AVG_LEN) v_count++;
    float v_sum = 0;
    for (int i = 0; i < v_count; i++) v_sum += v_history[i];
    sensor.batt_volt = v_sum / v_count;

    sensor.batt_perc = voltageToSOCNonLinear(sensor.batt_volt);
    log_i("V_Bat: ", sensor.batt_volt);
    log_i("Bat_perc: ", sensor.batt_perc);
  }
}

static float apply_altitude_correction(float pressure_hpa, float temp_c, float altitude_m) {
  // Lightweight approximation of the barometric altitude correction. (−2664 Byte flash)
  // For the typical Breezedude altitude range, a 2nd-order expansion avoids
  // pulling in powf() while staying close to the original result.
  static float last_altitude = -100000.0f;
  static int16_t last_temp_tenths = INT16_MIN;
  static float last_factor = 1.0f;

  if (altitude_m < 0.0f) {
    return pressure_hpa;
  }

  int16_t temp_tenths = (int16_t)(temp_c * 10.0f);
  if ((altitude_m != last_altitude) || (temp_tenths != last_temp_tenths)) {
    const float lapse_times_alt = 0.0065f * altitude_m;
    const float denom = temp_c + lapse_times_alt + 273.15f;
    if (denom > 0.0f) {
      const float x = lapse_times_alt / denom;
      if (x > 0.0f && x < 0.25f) {
        const float x2 = x * x;
        last_factor = 1.0f + (5.257f * x) + (16.45f * x2);
      } else {
        last_factor = 1.0f;
      }
    } else {
      last_factor = 1.0f;
    }
    last_altitude = altitude_m;
    last_temp_tenths = temp_tenths;
  }

  return pressure_hpa * last_factor;
}


// Sensors ----------------------------------------------------------------------------------------------------------------------
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

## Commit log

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2025-09-24 V2.3: * Added 10k pullup to Ssensor UART RX to aboid wakeup when no sensor is connected/cable failiure * Replaced CN3063 with TP4057 for better avaliability. * Moved SWD connector for better acessibi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
    [breezedude_mini.kicad_pcb, breezedude_mini.kicad_sch]
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2026-03-17 0.7 alpha, restructure, fix macOS filesystem
    [defines.h, main.cpp]
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2026-03-30 fixed filesystem not writable by samd21
    [logging.cpp, main.cpp, sensors.cpp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]
2026-03-31 fix baro values not being set. Add LBT mode, add analog sensor test mode. Frame for hw_info message, wip.
    [main.cpp, sensors.cpp, sensors.h]
2026-04-08 add HW info messages (beta), possibly fix WS85 unavailability issues due to powering down cause of bad voltage readings
    [main.cpp, tools.cpp, tools.h]
2026-04-10 add smart rx & forwarding. skip weather sending if no valid data
    [main.cpp, tools.cpp]
2026-05-02 fix 7mA during deepsleep issue
    [main.cpp, tools.cpp]
2026-05-04 fix ota not finishing
    [main.cpp]
2026-05-26 fix WS80 reading stops
    [main.cpp, sensors.cpp]
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2026-06-11 possibly fix wrong baro values if no humidity sensor present
    [main.cpp]
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2026-08-31 Cut flash by 13.4 kB, fix time-wrap and buffer bugs
    Flash 108016 -> 94572 B (88.5% -> 77.4% of 122112), RAM 17760 -> 13000 B.
    Size:
    * TinyUSB: only the CDC device class is used, but the Adafruit SAMD port
    enables MSC/HID/MIDI/VENDOR/VIDEO unconditionally and usbd.c references
    every class driver from a static table, so --gc-sections cannot drop them.
    Point the build at include/breezedude_tusb_config.h via CFG_TUSB_CONFIG_FILE
    (-7.3 kB flash, -1.9 kB RAM), leaving the framework package untouched.
    * hist: replace sinf/cosf with a Q15 quarter-wave table and accumulate the
    direction vector in int32_t. These were the only callers of the libm range
    reduction, so __ieee754_rem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
2026-08-31 Stop blocking on the debug UART after every log call
    Uart::flush() on the SAMD core busy-waits until the whole TX ring buffer has
    been shifted out, roughly 87 us per character at 115200 baud. Every log_*
    helper called it, so a single line such as log_i("Wakeup: ", time()) held the
    CPU for over a millisecond and log_v_hex_dump() did it once per byte - a
    24 byte FANET packet meant 24 full flush cycles.
    Removed from the ten per-call helpers; log_flush() keeps it. The UART only
    has to be drained before the MCU sleeps, since the SERCOM clocks stop in
    standby, and before a reset. sleep() now calls log_flush() unconditionally
    instead of only when USB happens to be connected, which also fi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
2026-08-31 Restore RESET as a soft reset
    RESET is deliberately not a hard reset: it re-runs setup() so the web debug
    tool gets the full boot output while the USB device stays enumerated. That
    tool sends RESET=1 right after connecting, so making it a real reset drops
    the CDC link, the tool reconnects, sends RESET=1 again, and the device sits
    in a reconnect loop. When USB is plugged in the physical reset button is
    right there anyway, and REBOOT remains the hard reset.
    This reverts the RESET half of "The RESET command re-entered setup() instead
    of resetting" from 9d3e376. That finding was wrong: I claimed re-entering
    setup() appends the altitude to the station name a second time, but
    parse_file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
2026-08-31 Add CDC settings editor: change settings.txt parameters over USB
    Lets a host tool change individual parameters in the flash settings.txt
    without uploading a whole file. The read-modify-write already existed as
    update_multiple_settings_in_flash() (used by the LoRa config-update path);
    this adds the console side.
    Commands, one per line, replies carry a fixed prefix so a host can parse them:
    DUMP -> DUMP BEGIN / raw settings.txt / DUMP END
    SET KEY=VALUE -> stage one change "SET OK NAME (2/16 staged)"
    SETLIST -> list staged changes
    SETCLEAR -> discard staged changes
    SAVE -> write all staged changes in one erase cycle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
2026-09-01 Allow patching an empty settings block, add whole-file write over CDC
    Two things blocked configuring a device over the console.
    update_multiple_settings_in_flash() refused to touch a settings block that
    was empty or shorter than 100 bytes, on the assumption that a short block
    meant a truncated file. That heuristic blocked exactly the cases where
    patching is most useful: a factory device carrying only a dummy line, and a
    station whose configuration is damaged and needs repairing over USB. An empty
    or unreadable block is now treated as an empty document and the given keys are
    appended to it, which also lets a signature-verified LoRa config update
    provision a blank device.
    Second,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
2026-09-02 Add STATUS, a second console on the debug UART, BOOTLOADER and TIME_SKIP
    Groundwork for a hardware-in-the-loop test rig. All four are ordinary console
    commands in the release build - no test build, so what gets tested is what
    ships.
    * STATUS prints one JSON line: firmware and bootloader version, FANET id,
    station name, sensor/LoRa/baro types, uptime, reset cause, battery, data
    ages, measurements, LBT counter, OTA slot and a free-RAM estimate.
    This replaces log scraping. breezedude-analyze.js currently recovers four of
    these values with eight separate regexes over the boot log, and a rig would
    have reimplemented the same guesswork. Numbers are scaled integers (mV, Pa,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
2026-09-05 Mark every log line with its level: E|W|I|D
    The station's console was a wall of equally weighted lines. In a long
    endurance run you are looking for the few places where something went wrong,
    and the keyword guessing in the evaluation took "V_Batt read error: " for a
    fault while missing "CRC error".
    Every line now carries its classification:
    E| endangers regular operation (flash write failure, missing mandatory
    settings, settings.txt overflow, no radio module, deep undervoltage,
    restart because wind data went stale)
    W| a fault that does not weigh heavily (rejected packet, missing optional
    sensor, discarded command, skipped transmission)
    I| normal opera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
2026-09-05 Optional wakeup on the debug UART, behind UART_WAKE
    Without this the console on the debug UART is only usable for about two
    seconds after a reset. The SERCOM clocks stop in standby, so anything that
    arrives while the station sleeps is lost outright and is never processed
    later. Measured on the rig: of sixty requests sent one per second, two were
    answered - the two inside that window - and not one of the other fifty-eight
    ever produced a late reply.
    The mechanism already existed for SERCOM0, where the sensor UART uses it.
    enable_sercom1_int() mirrors it for the debug UART: GCLK2 on OSCULP32K with
    RUNSTDBY, RUNSTDBY on the SERCOM, and SFDE so start-of-frame detection raises
    an inter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
2026-09-11 WIP: standby UART, sensor power guards and a shorter wake cycle
    - Debug UART configured once for reception in standby (UART_WAKE=1), on
    OSC8M, without clock switching on sleep and wake; the baud register is no
    longer recomputed in arithmetic mode (528 baud, watchdog reset loop)
    - OSC8M released when UART_WAKE is off; DMAC clock register fix; dead
    PM_sleep() removed
    - Sensor supply: SERCOM0 ended before its pins are released and not armed
    without supply; WS_POWER and SLEEPQUIET runtime test commands
    - No fixed 100 ms awake time after a wakeup; battery and barometer read
    only before a transmission, the barometer conversion started ahead
    - OTA offer window 15 s -> 5 s, and th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
2026-09-15 Cut the synchronisation waits out of the wake path
    A DAVIS wake took 113 ms above 1 mA. Most of it was waiting: every
    synchronised access to a peripheral clocked from GCLK6 - the RTC, the TC3
    pulse counter, the TC4 time counter, the watchdog - waits about 5 ms for the
    synchroniser at 1024 Hz, and the wake path was full of them. Radio sleep
    (1.6 ms) and the direction ADC (1.0 ms) were not worth touching.
    Waits taken out:
    - rtc_sleep_cfg() routed GCLK6 to the RTC again before every sleep, five
    synchronised writes for a routing nothing ever undoes. Once is enough.
    After the first full configuration only COUNT and PER are written,
    instead of disable, software reset, co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
2026-09-15 Run GCLK6 at 8192 Hz and let the timers run free
    After the previous commit a DAVIS wake still took 69 ms above 1 mA, and most
    of it was still synchronisation: each access to the RTC, TC3, TC4 or the
    watchdog waits about 5 ms at 1024 Hz. At 8192 Hz it is about 0.6 ms.
    The faster clock is not free. Measured on the rig, clocking the RTC or a
    timer faster than 1024 Hz costs about 13.5 uA of sleep current - the same at
    8192 Hz as at 32.768 kHz, the RTC alone as much as all three - and
    READREQ.RCONT on a single timer at 1024 Hz costs just as much. The costs do
    not add up. So rather than choosing between a faster clock and avoiding the
    waits in software, both are done and the standing cos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
2026-09-15 Wake-phase profiler behind WAKE_PROFILE
    This is what showed where the awake time of the two previous commits went.
    wake_mark() stores micros() at fixed points of a wake cycle, and once per
    cycle a line gives the time between them in 0.1 ms:
    PROF d1 slp6 pc1 dir10 wu2 loop0 tts0 log1 rtc3 rad16 arm1 enq19 fl162 pre0 tot228
    That one is a DAVIS wake at 8192 Hz. 16 of its 23 ms are the UART draining
    the log, which is what bounds the wake now. wake_profile.h documents the
    fields and where each mark sits.
    Only built with -DWAKE_PROFILE, which costs 408 bytes of flash and 24 bytes
    of RAM. Without it wake_mark() and wake_profile_report() are empty inline
    functions, and the release i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
2026-09-15 WS85_TRACE: debug firmware for the WS85 UART wake path
    The build that found the faults fixed in the previous commit, kept for the
    next time a UART sensor loses data after a wakeup. Everything sits behind
    -DWS85_TRACE; the release image comes out byte for byte the same with and
    without this commit.
    Three kinds of line, documented field by field, with examples recorded on the
    rig, in the comment above ws85_trace_report() in sensors.cpp:
    W85 ref once after boot: 25 s of what the sensor sends while the station
    stays awake, burst by burst with the CRC checked - the reference
    W85 q= per wake cycle: the SERCOM0 flags as the wakeup found them, the
    interr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
2026-09-16 WS85 UART: take a frame with a stray byte in front
    One frame in five, and one in eight, still went missing after the previous
    commit. The trace showed what the receiver had delivered:
    seen=32[E0 1C 00 85 00 04 ...] res=crc
    The wakeup had cost the usual two bytes, but in their place stood E0 - a byte
    the receiver decoded out of step. Switched on in the middle of a byte it takes
    the next edge for a start bit, and when the stop bit position happens to be
    high, the result is passed on as a byte. The parser had no guess for that: it
    only counted how many bytes were missing.
    A frame is now taken from the end. The end of it arrives intact - what the
    wakeup costs is its beginning -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
2026-09-16 WS85_TRACE: show how the parser got its frame
    The W85 q= line gets a frame= field: put<n> head bytes put in front of the
    burst, rep<n> received bytes overwritten with the head, drop<n> bytes dropped
    in front, and none when no frame came out.
    ... seen=31[1C 00 85 00 04 ...] t1=821 t2=3034 frame=put2 res=ok
    It tells a frame the wakeup only shortened from one that also carried a byte
    decoded out of step - the case the previous commit is about. Over 240 s on the
    rig: put2 fourteen times, put3 twice, put4 ten times, nothing else.
    The host test builds a second time with -DWS85_TRACE and checks the field
    against the same bursts. The release image is byte for byte the same with and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
2026-09-24 Repeater: listen when the next packet is due, not all the time
    A repeater has to hear everything, so it listens continuously. Measured on the
    rig: the receiver alone draws 5.0 mA, the station 5.30 mA against 0.28 mA with
    the radio asleep - 127 mAh a day instead of 20.
    For a repeater that only has to pass on weather packets, nearly all of that is
    spent on silence. A weather station sends on its own clock, last send plus its
    interval, and that rhythm is stable: the rig station, set to 40 s, sends every
    39.65 s with the intervals within 10 ms of each other. What makes it usable is
    that the repeater measures the period with its own clock, so the constant error
    between the two oscillato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
2026-10-17 Logs: say what went wrong where the station was silent, or said too much
    A pass over the error paths, after a barometer that never answered showed how
    little the log told. Each of these used to end in nothing, in a red LED, or in
    a line that could not be acted on:
    - startTransmit() was never checked. A refused packet counted as sent, waited
    3.5 s for a TX-done that does not come and left "Send timed out" behind.
    Now "TX start failed, code=N" with the RadioLib code, and the job is retried
    like a deferral.
    - radio_init() said "No LoRa found" for a missing chip and for a refused
    parameter alike. The LLCC68 begin() code is logged first: -2 is a missing
    chip, -12 a bandwidth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
2026-10-17 Hardware detection: let the battery divider overrule the ID pin
    The ID pin was trusted on its own, and on a board that is not 2.5 it can be
    low for reasons of its own: alpha 1.4 has PA27 on an SPI chip select, and a
    pad with capacitance on it reads low before the weak pull-up has charged it.
    A revision picked wrongly reads the battery from an open pin - a dead cell,
    as far as the firmware can tell - and the station goes into undervoltage
    sleep with USB switched off. That fits what the first board to boot this
    firmware showed: USB error 43, nothing answering, the bootloader still fine.
    hw_detect() now reads the ID pins three times after a 10 ms settle, and then
    samples the battery d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
2026-10-17 Baro: no bus probing, and free a stuck I2C slave at boot
    The first read that came back empty used to probe the bus for the ID
    registers of the other barometer chips, with repeated-start reads the chip
    at 0x76 did not expect. One board answered by holding the bus. The SAMD Wire
    library has no timeout, so the station hung - and after a reset it hung again
    right after "Radio:", in init_baro(), because an I2C slave caught in the
    middle of a transfer survives an MCU reset and keeps SDA low until it sees
    clocks. Reflashing did not help either, only cutting the power did. USB
    never came up on that board because setup() never finished.
    The probe is gone. The one line it was for now says wh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
2026-10-17 HP203B: wait out the soft reset, so the first reading of a boot is not lost
    The first barometer reading after every boot came back empty, every later
    one worked. The driver only set its post-reset delay in getAddr_HP203B(),
    which nothing calls, so begin() issued the soft reset and waited 0 ms, and
    the conversion requested right after it was lost in the reset. Measured on
    two boards: a start 20 s before the read gave zeros, the restart from that
    failed read gave 1011 hPa. begin() sets the delay itself now.
    init_baro() no longer names the chip; print_settings() does that through
    baro_state_text(), and the line was printed twice.
2026-10-17 Analog test: show the direction in degrees next to the raw count
    The test printed the raw ADC count of the direction potentiometer and the
    pulse state. Whether the input still covers its whole range is hard to see in
    a raw count: an ADC input damaged by a lightning strike has answered with
    half the range before, and only a sweep that reads 0 to 359 at the far ends
    tells. The degrees - the same conversion the measurement uses, without the
    heading offset - now stand next to the count.
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2026-10-17 Console lines end with CR too, LBT never retries at once, awake time in the verbose log
    Three small things from the first field log of the compact format.
    "Serial cmd too long, discarded": the console ended a line only at LF. A
    sender that terminates with CR alone - terminal programs do, and the web
    analyser - never had a line evaluated, so its bytes piled up across wakeups
    until the buffer overflowed. CR ends a line now as well; the LF that may
    follow is an empty line and skipped.
    "just looping, will sleep" at a weather slot: with LBT on and a second
    station on the same 40 s grid, the channel is busy from time to time. The
    retry delay was drawn from 0 to 2000 ms, and at 0 the pa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
2026-10-17 HP203B: drive the bus with timeouts instead of the Wire library
    The Wire library of the SAMD core waits for ever on a bus that a slave holds,
    and a slave can die in the middle of a transfer at any time - not only at a
    reset, where i2c_bus_recover() now catches it. One hung station was enough.
    The driver now drives SERCOM3 itself: the same register sequence TwoWire
    uses in smart mode, start, address, bytes, ACK/NACK, stop - with every wait
    giving up after 5 ms and reporting failure. Wire.begin() still configures the
    peripheral; this only replaces the loops. A failed read leaves the value at
    0, which the barometer code already treats as "no data", and a chip that does
    not acknowledge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
2026-10-17 Resets counted across resets, the watchdog a test command, OTA waits asleep
    Stations in the field reset now and then with nobody watching. The reset
    cause was logged at boot and gone with the next one. A small record in
    .noinit RAM now survives every reset short of a power cycle: how many since
    the station last had power, how many by watchdog, system request, brown-out
    and the reset pin, and the cause of the latest. The boot log says it, STATUS
    shows it, and the HWInfo payload can carry it.
    WDT is a command now, not a setting: it is not stored and does not appear in
    a DUMP, so nobody turns the watchdog off by editing a configuration. A
    station in the field always runs with it; the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
2026-10-17 HWInfo: resets, awake duty, hardware and bootloader in the report, a repeater report of its own
    The dynamic report (type 1) now carries the resets since power-on and the
    cause of the last one in the byte that was reserved, and an awake duty class
    in the free bits of the charger flags. The count wraps at 32 rather than
    saturating; a power cycle is told from a wrap by the cause code.
    The static report (type 3) gains the pin map the firmware chose, with the
    raw ID pins and whether the divider overruled them, and the bootloader
    version packed into two bytes.
    A new type 4 is sent every 15 minutes by stations with the repeater on: the
    receiver mode and duty, packets forwarded since the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
2026-10-26 Hardware detection: a divider pin at full scale no longer outvotes the ID pin
    The first 2.5 boards came up on the 2.4 pin map. Their ID pin was right
    (id 1), but the old divider pin PB08 read 4.19 V without any spread - full
    scale of the 1.0 V reference, which any pin above 1 V reaches - and that
    looked more like a battery than the real divider on PB02, which wobbled
    on the charger-only supply. A clipped reading now counts as no evidence,
    so it can never overrule the ID pin.
    When the two still disagree, the boot log shows both pins with their
    spread or "full scale" in one line; otherwise it keeps showing only the
    divider in use.
2026-10-28 Sensor supply: switch it on again after a brownout cut it
    The BOD33 handler cuts the WSxx/WS85 supply (PB03 high) and releases the
    UART pins, but switch_sensor_power() kept current_power_state = true and
    took every later request to switch on as already done. After one brownout
    - a transmission on a weak battery, or a board on a charger without a
    battery - the sensor stayed dark until the next reset, and the station
    sent no weather.
    The handler now raises bod33_sensor_cut; switch_sensor_power() clears its
    state and the sensor UART when it sees it, logs the cut, and the next
    battery reading before a transmission switches the sensor on again.
2026-10-28 TESTMODE: send the test values without any wind sample
    The test values replace the wind anyway, but the packet was dropped
    before that when the wind history was empty ("No valid wind data" in
    1.1.2, "No wind sample in the last" now) - which it always is without a
    sensor attached, the case TESTMODE exists for. A wind sensor type still
    has to be configured.
2026-10-28 Sensor supply: mask the brownout interrupt while a UART sensor powers up
    On a 2.3 board with a WS80 the sensor never came up: switching it on
    dipped the supply below the BOD33 level, the brownout handler cut it off
    again at once, and every retry went the same way ("WS sensor power ON",
    "Sensor supply was cut by a brownout", gate back at 3.3 V).
    For the UART sensors, which stay powered, the BOD33 interrupt is now
    masked for 20 ms while the supply comes up; a dip in that window is
    logged, the flag is cleared and the interrupt armed again, so a real
    brownout afterwards is still caught. The Davis, whose supply is switched
    for every direction reading, is left as it was.
2026-10-28 Console: stay awake until a debug UART command line has arrived
    With UART_WAKE=1 the start bit of a command woke the station, which had
    nothing else to do and slept again after a millisecond ("wake CONSOLE ...
    awake 1 ms") - before the rest of "STATUS" was on the wire, about 0.7 ms
    at 115200 baud. The command was never answered.
    A console wakeup now allows sleep only 5 ms later, so the byte that woke
    it lands, and the loop does not sleep while a debug UART line has begun
    but not ended - for at most 100 ms after its last byte, so noise or a
    pulled cable cannot keep the station awake.
2026-10-28 Console: cap the wait for a debug UART line, drop a line given up on
    A line that never ends no longer holds the station awake: besides the
    100 ms since the last byte, the wait ends 1 s after the line's first byte,
    so a noisy RX line that keeps delivering bytes cannot keep it up. The
    part of a line that was given up on is dropped when the next bytes come
    in, instead of being glued in front of the next command.
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2026-10-28 WS80: end the block read at Humi
    Light, UV, the missing pressure sensor and the sensor's supply voltage
    follow the Humi line and are not sent anywhere; reading them kept the CPU
    awake for about a fifth of every 4.75 s block. A WS80 block - recognised
    by its Temperature line - now completes at Humi and the station goes
    back to its timed sleep. A WS85 has no Humi line and still ends at
    BatVoltage, so one still being auto-detected is never cut short.
2026-10-28 WS80/WS85 text sensor: keep the block across wakeups, learn its period
    The parse state of read_wsxx() was local to one call. A block that paused
    for longer than the read window - the sensor reads its SHT30 and Si1132
    in the middle of one - was lost from the pause on: the next call waited
    for a header that had long gone by. The state now lives across calls and
    a block that stays quiet for 300 ms is given up on.
    A station that woke too late for the header also takes the WindDir line
    as the start of a block, so wind, temperature and humidity are still
    read; such a block does not count for the period.
    The sleep without listening after a block used to be a fixed 4685 ms
    (8350 ms for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
